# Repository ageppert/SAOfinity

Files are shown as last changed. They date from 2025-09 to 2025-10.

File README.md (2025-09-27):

# SAOfinity

An SAO display solution, with options!

-------------

# V1.0 First Draft - Shared at Hackaday Supercon.9 in 2025

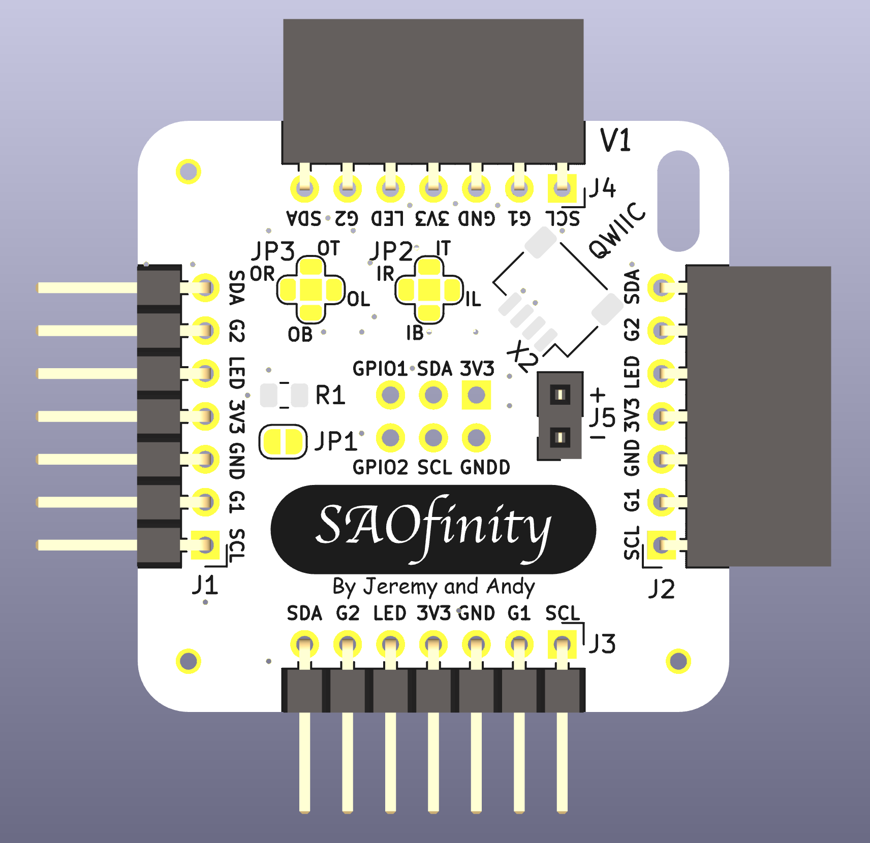
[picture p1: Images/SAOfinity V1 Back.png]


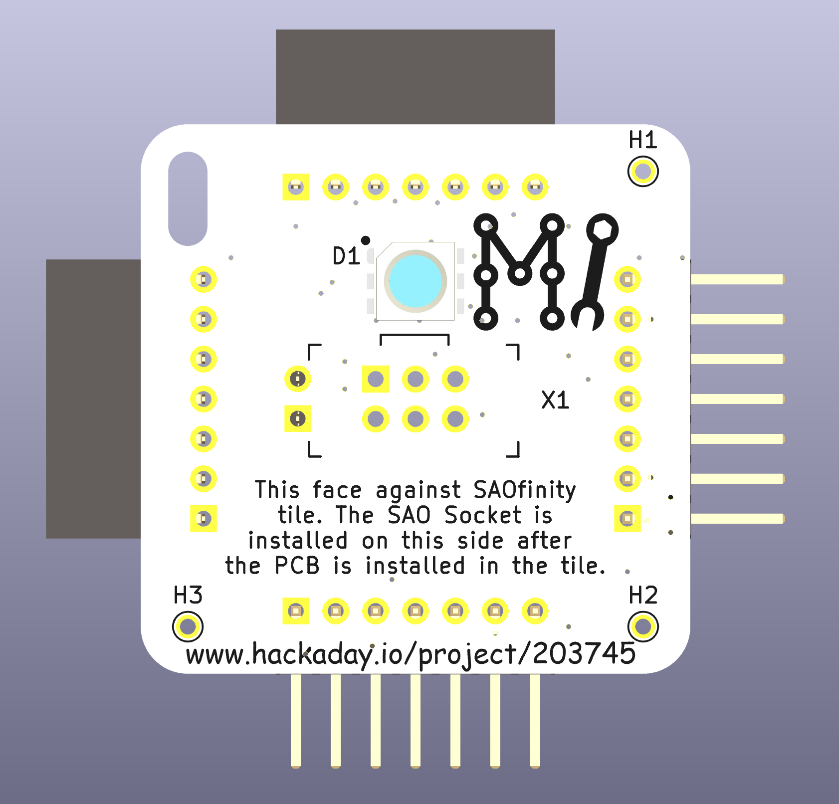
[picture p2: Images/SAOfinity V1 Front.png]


The SAO DEMO CONTROLLER is available for purchase here: https://www.tindie.com/products/36033/

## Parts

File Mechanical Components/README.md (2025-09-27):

# MECHANICAL COMPONENTS

3D printable SAOfinity components coming soon...

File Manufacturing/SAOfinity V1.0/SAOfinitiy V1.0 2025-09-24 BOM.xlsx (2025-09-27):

Comment | Designator | Footprint | LCSC Part Number | Substituted
WS2813C | D1 | LED_WS2813_PLCC6_5.0x5.0mm_P1.6mm_Core64_Abg_Mod | C5359034

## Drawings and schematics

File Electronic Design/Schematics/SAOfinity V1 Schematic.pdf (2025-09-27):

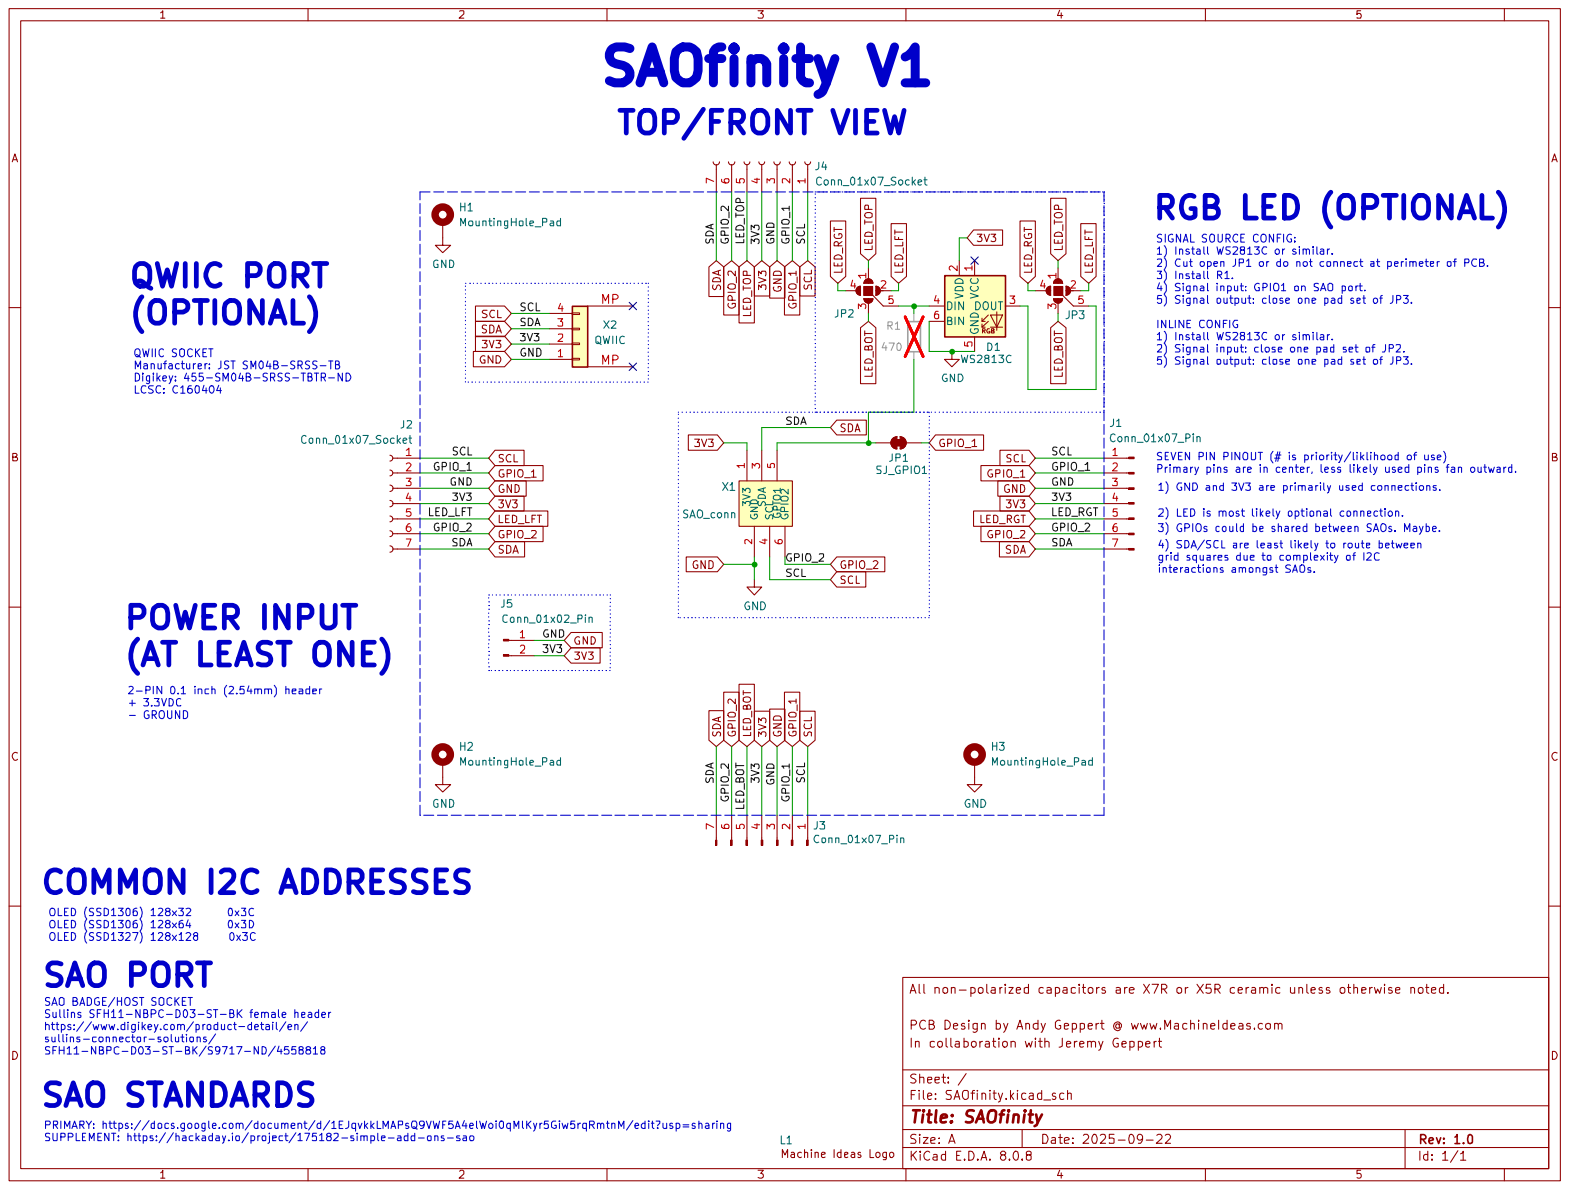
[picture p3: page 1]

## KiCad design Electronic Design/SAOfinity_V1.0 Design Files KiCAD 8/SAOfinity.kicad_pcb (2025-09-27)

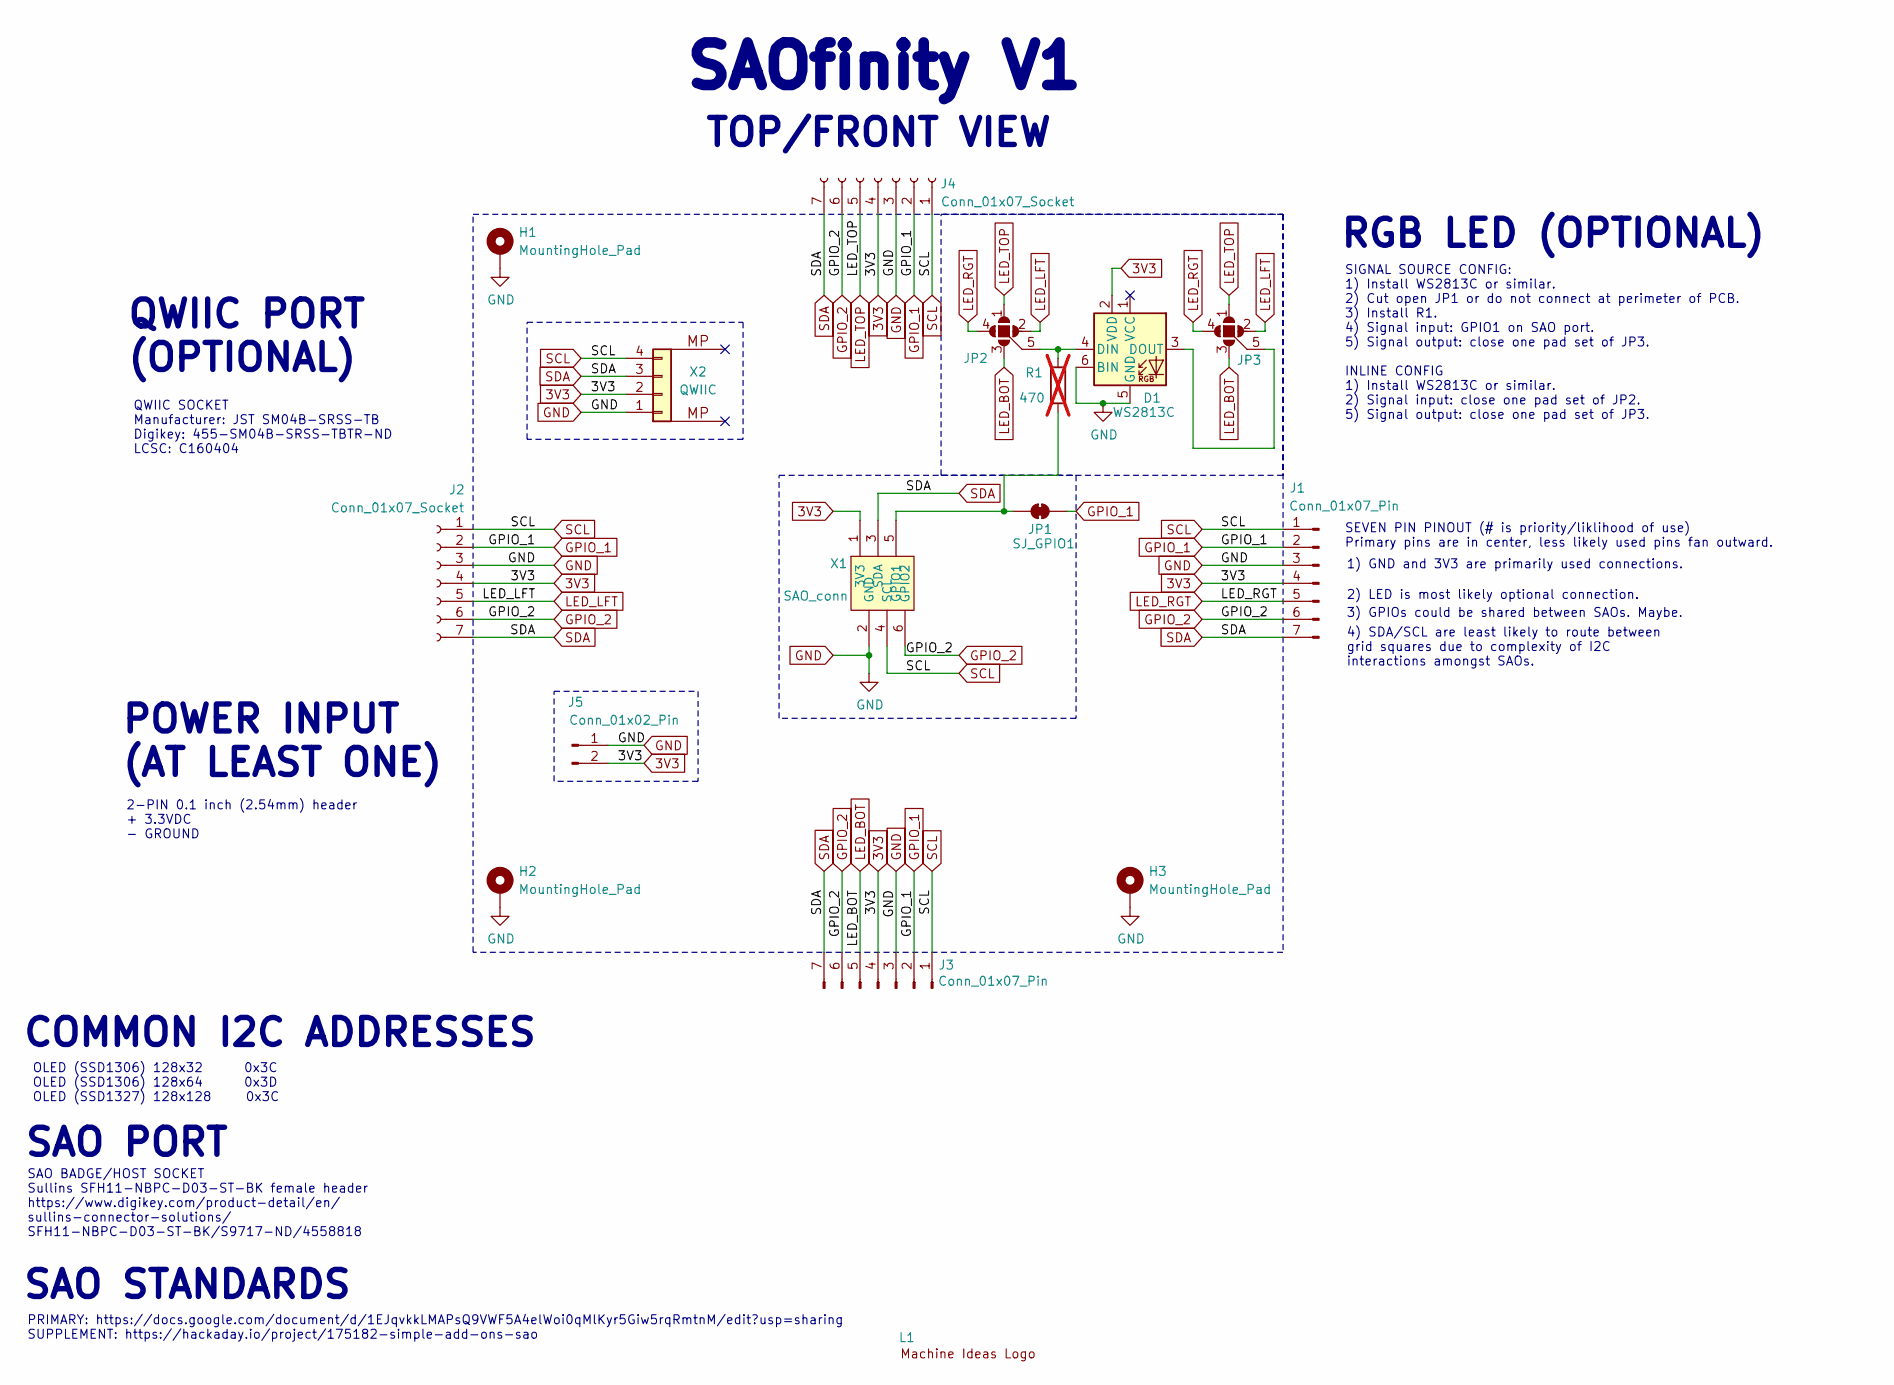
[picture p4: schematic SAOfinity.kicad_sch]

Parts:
D1: WS2813C; LED_WS2813_PLCC6_5.0x5.0mm_P1.6mm_Core64_Abg_Mod; JLCPCB P/N C5359034
H1, H2, H3: MountingHole_Pad; TestPoint_THTPad_D1.5mm_Drill1.0mm
J1, J3: Conn_01x07_Pin; PinHeader_1x07_P2.54mm_Horizontal
J2, J4: Conn_01x07_Socket; PinSocket_1x07_P2.54mm_Horizontal
J5: Conn_01x02_Pin; PinSocket_1x02_P2.54mm_Vertical
JP1: SJ_GPIO1; SolderJumper-2_P1.3mm_Bridged_RoundedPad1.0x1.5mm
JP2, JP3: SolderJumper_5_Open; SolderJumper-5_P1.3mm_Open_RoundedPad1.0x1.5mm_NumberLabels
L1: Machine_Ideas_logo
R1: 470; R_0805_2012Metric; LCSC C17710; not fitted
X1: SAO_conn; Badgelife-SAOv169-BADGE-2x3-no-front-text-yes-front-outline; MPN SFH11-NBPC-D03-ST-BK
X2: QWIIC; JST_SH_SM04B-SRSS-TB_1x04-1MP_P1.00mm_Horizontal; MPN SM04B-SRSS-TB; LCSC C160404

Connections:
3V3: D1.2 (VDD), J1.4, J2.4, J3.4, J4.4, J5.2, X1.1 (3V3), X2.2
GND: D1.5 (GND), D1.6 (BIN), H1.1, H2.1, H3.1, J1.3, J2.3, J3.3, J4.3, J5.1, X1.2 (GND), X2.1
GPIO_1: J1.2, J2.2, J3.2, J4.2, JP1.2 (B)
GPIO_2: J1.6, J2.6, J3.6, J4.6, X1.6 (GPIO2)
LED_BOT: J3.5, JP2.3 (C), JP3.3 (C)
LED_LFT: J2.5, JP2.2 (B), JP3.2 (B)
LED_RGT: J1.5, JP2.4 (D), JP3.4 (D)
LED_TOP: J4.5, JP2.1 (A), JP3.1 (A)
unnamed: D1.4 (DIN), JP2.5 (E), R1.2
unnamed: D1.3 (DOUT), JP3.5 (E)
unnamed: JP1.1 (A), R1.1, X1.5 (GPIO1)
SCL: J1.1, J2.1, J3.1, J4.1, X1.4 (SCL), X2.4
SDA: J1.7, J2.7, J3.7, J4.7, X1.3 (SDA), X2.3

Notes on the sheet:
RGB LED (OPTIONAL)
SAO BADGE/HOST SOCKET Sullins SFH11-NBPC-D03-ST-BK female header https://www.digikey.com/product-detail/en/ sullins-connector-solutions/ SFH11-NBPC-D03-ST-BK/S9717-ND/4558818
COMMON I2C ADDRESSES
QWIIC SOCKET Manufacturer: JST SM04B-SRSS-TB Digikey: 455-SM04B-SRSS-TBTR-ND LCSC: C160404
3) GPIOs could be shared between SAOs. Maybe.
2) LED is most likely optional connection.
4) SDA/SCL are least likely to route between grid squares due to complexity of I2C interactions amongst SAOs.
POWER INPUT (AT LEAST ONE)
OLED (SSD1306) 128x32 0x3C OLED (SSD1306) 128x64 0x3D OLED (SSD1327) 128x128 0x3C
SEVEN PIN PINOUT (# is priority/liklihood of use) Primary pins are in center, less likely used pins fan outward.
SAO STANDARDS
PRIMARY: https://docs.google.com/document/d/1EJqvkkLMAPsQ9VWF5A4elWoi0qMlKyr5Giw5rqRmtnM/edit?usp=sharing SUPPLEMENT: https://hackaday.io/project/175182-simple-add-ons-sao
TOP/FRONT VIEW
QWIIC PORT (OPTIONAL)
1) GND and 3V3 are primarily used connections.
2-PIN 0.1 inch (2.54mm) header + 3.3VDC - GROUND
SAO PORT
SIGNAL SOURCE CONFIG: 1) Install WS2813C or similar. 2) Cut open JP1 or do not connect at perimeter of PCB. 3) Install R1. 4) Signal input: GPIO1 on SAO port. 5) Signal output: close one pad set of JP3. INLINE CONFIG 1) Install WS2813C or similar. 2) Signal input: close one pad set of JP2. 5) Signa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
SAOfinity V1

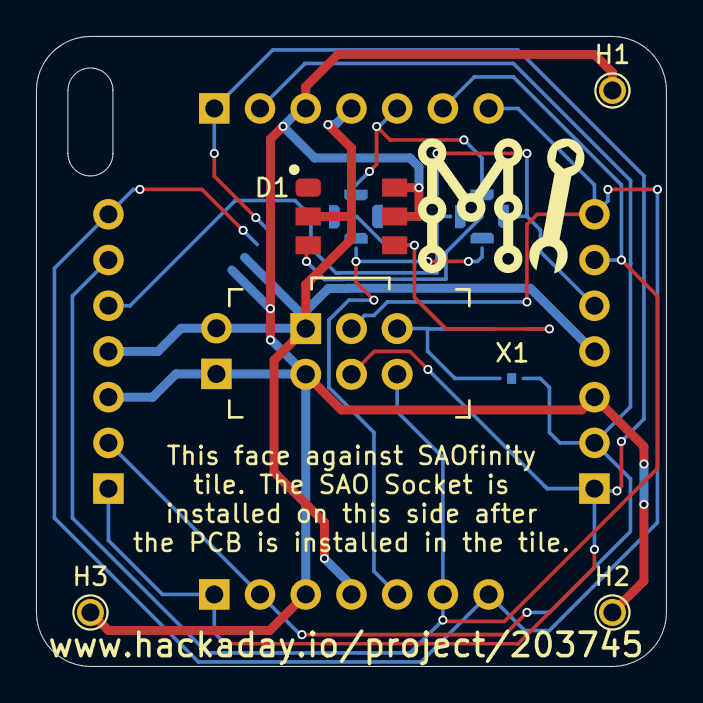
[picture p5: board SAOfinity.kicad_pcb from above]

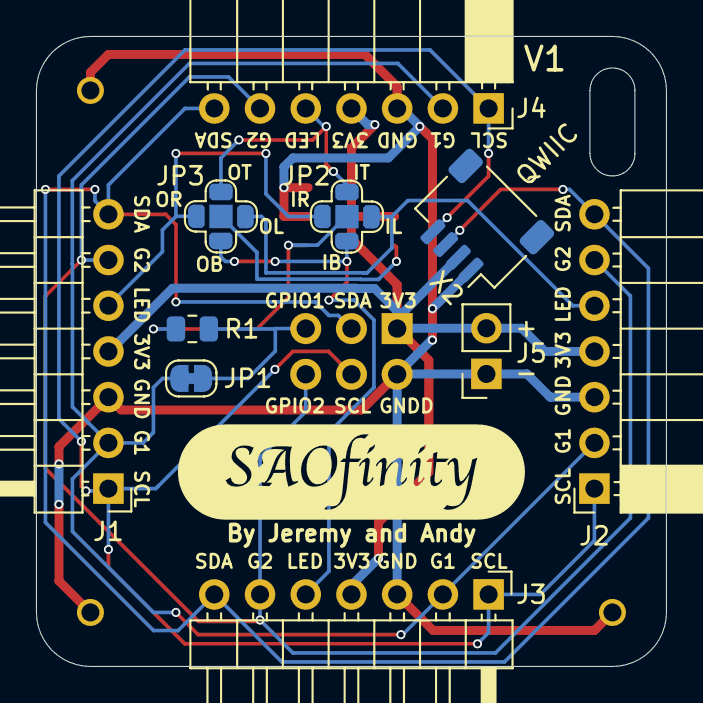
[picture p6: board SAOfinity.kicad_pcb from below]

Board: 2 copper layers, 35.0 x 35.0 mm, 17 parts (11 on the bottom side), 13 nets.

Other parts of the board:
kibuzzard-68D4AC2E: G***; kibuzzard-68D4AC2E

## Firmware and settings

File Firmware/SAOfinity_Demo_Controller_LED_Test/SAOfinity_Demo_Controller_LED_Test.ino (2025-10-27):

/*
This is Adafruit's "strandtest_nodelay" with small modifications by Andy to work with the SAO Demo Controller and SAOfinity.
SAOfinity: https://hackaday.io/project/203745-saofinity
SAO Demo Controller: https://hackaday.io/project/198034-sao-demo-controller 
First board in the SAOfinity strip needs a few mods and resistors to be the "source" for the strip. Details on SAOfinity page linked above.
Use Pin 1 for output to the LEDs from the SAO Demo Controller. Configured for 6x6 36 tile demo.
*/

// A non-blocking everyday NeoPixel strip test program.

// NEOPIXEL BEST PRACTICES for most reliable operation:
// - Add 1000 uF CAPACITOR between NeoPixel strip's + and - connections.
// - MINIMIZE WIRING LENGTH between microcontroller board and first pixel.
// - NeoPixel strip's DATA-IN should pass through a 300-500 OHM RESISTOR.
// - AVOID connecting NeoPixels on a LIVE CIRCUIT. If you must, ALWAYS
//   connect GROUND (-) first, then +, then data.
// - When using a 3.3V microcontroller with a 5V-powered NeoPixel strip,
//   a LOGIC-LEVEL CONVERTER on the data line is STRONGLY RECOMMENDED.
// (Skipping these may work OK on your workbench but can fail in the field)

#include <Adafruit_NeoPixel.h>
#ifdef __AVR__
 #include <avr/power.h> // Required for 16 MHz Adafruit Trinket
#endif

// Which pin on the Arduino is connected to the NeoPixels?
// On a Trinket or Gemma we suggest changing this to 1:
#ifdef ESP32
// Cannot use 6 as output for ESP. Pins 6-11 are connected to SPI flash. Use 16 instead.
#define LED_PIN    16
#else
#define LED_PIN    1
#endif

// How many NeoPixels are attached to the Arduino?
#define LED_COUNT 36

// Declare our NeoPixel strip object:
Adafruit_NeoPixel strip(LED_COUNT, LED_PIN, NEO_GRB + NEO_KHZ800);
// Argument 1 = Number of pixels in NeoPixel strip
// Argument 2 = Arduino pin number (most are valid)
// Argument 3 = Pixel type flags, add together as needed:
//   NEO_KHZ800  800 KHz bitstream (most NeoPixel products w/WS2812 LEDs)
//   NEO_KHZ400  400 KHz (classic 'v1' (not v2) FLORA pixels, WS2811 drivers)
//   NEO_GRB     Pixels are wired for GRB bitstream (most NeoPixel products)
//   NEO_RGB     Pixels are wired for RGB bitstream (v1 FLORA pixels, not v2)
//   NEO_RGBW    Pixels are wired for RGBW bitstream (NeoPixel RGBW products)

unsigned long pixelPrevious = 0;        // Previous Pixel Millis
unsigned long patternPrevious = 0;      // Previous Pattern Millis
int           patternCurrent = 0;       // Current Pattern Number
int           patternInterval = 5000;   // Pattern Interval (ms)
bool          patternComplete = false;

int           pixelInterval = 50;       // Pixel Interval (ms)
int           pixelQueue = 0;           // Pattern Pixel Queue
int           pixelCycle = 0;           // Pattern Pixel Cycle
uint16_t      pixelNumber = LED_COUNT;  // Total Number of Pixels

// setup() function -- runs once at startup --------------------------------
void setup() {
  // These lines are specifically to support the Adafruit Trinket 5V 16 MHz.
  // Any other board, you can remove this part (but no harm leaving it):
#if defined(__AVR_ATtiny85__) && (F_CPU == 16000000)
  clock_prescale_set(clock_div_1);
#endif
  // END of Trinket-specific code.

  delay(500);               // Delay to avoid issues with data line on the NeoPixels, doesn't seem to help.
  strip.begin();           // INITIALIZE NeoPixel strip object (REQUIRED)
  strip.show();            // Turn OFF all pixels ASAP
  strip.setBrightness(50); // Set BRIGHTNESS to about 1/5 (max = 255)
}

// loop() function -- runs repeatedly as long as board is on ---------------
void loop() {
  unsigned long currentMillis = millis();                     //  Update current time
  if( patternComplete || (currentMillis - patternPrevious) >= patternInterval) {  //  Check for expired time
    patternComplete = false;
    patternPrevious = currentMillis;
    patternCurrent++;                                         //  Advance to next pattern
    if(patternCurrent >= 7)
      patternCurrent = 0;
  }

  if(currentMillis - pixelPrevious >= pixelInterval) {        //  Check for expired time
    pixelPrevious = currentMillis;                            //  Run current frame
    switch (patternCurrent) {
      case 7:
        theaterChaseRainbow(50); // Rainbow-enhanced theaterChase variant
        break;
      case 6:
        rainbow(10); // Flowing rainbow cycle along the whole strip
        break;     
      case 5:
        theaterChase(strip.Color(0, 0, 127), 50); // Blue
        break;
      case 4:
        theaterChase(strip.Color(127, 0, 0), 50); // Red
        break;
      case 3:
        theaterChase(strip.Color(127, 127, 127), 50); // White
        break;
      case 2:
        colorWipe(strip.Color(0, 0, 255), 50); // Blue
        break;
      case 1:
        colorWipe(strip.Color(0, 255, 0), 50); // Green
        break;        
      default:
        colorWipe(strip.Color(255, 0, 0), 50); // Red
        break;
    }
  }
}

// Some functions of our own for creating animated effects -----------------

// Fill strip pixels one after another with a color. Strip is NOT cleared
// first; anything there will be covered pixel by pixel. Pass in color
// (as a single 'packed' 32-bit value, which you can get by calling
// strip.Color(red, green, blue) as shown in the loop() function above),
// and a delay time (in milliseconds) between pixels.
void colorWipe(uint32_t color, int wait) {
  static uint16_t current_pixel = 0;
  pixelInterval = wait;                        //  Update delay time
  strip.setPixelColor(current_pixel++, color); //  Set pixel's color (in RAM)
  strip.show();                                //  Update strip to match
  if(current_pixel >= pixelNumber) {           //  Loop the pattern from the first LED
    current_pixel = 0;
    patternComplete = true;
  }
}

// Theater-marquee-style chasing lights. Pass in a color (32-bit value,
// a la strip.Color(r,g,b) as mentioned above), and a delay time (in ms)
// between frames.
void theaterChase(uint32_t color, int wait) {
  static uint32_t loop_count = 0;
  static uint16_t current_pixel = 0;

  pixelInterval = wait;                   //  Update delay time

  strip.clear();

  for(int c=current_pixel; c < pixelNumber; c += 3) {
    strip.setPixelColor(c, color);
  }
  strip.show();

  current_pixel++;
  if (current_pixel >= 3) {
    current_pixel = 0;
    loop_count++;
  }

  if (loop_count >= 10) {
    current_pixel = 0;
    loop_count = 0;
    patternComplete = true;
  }
}

// Rainbow cycle along whole strip. Pass delay time (in ms) between frames.
void rainbow(uint8_t wait) {
  if(pixelInterval != wait)
    pixelInterval = wait;                   
  for(uint16_t i=0; i < pixelNumber; i++) {
    strip.setPixelColor(i, Wheel((i + pixelCycle) & 255)); //  Update delay time  
  }
  strip.show();                             //  Update strip to match
  pixelCycle++;                             //  Advance current cycle
  if(pixelCycle >= 256)
    pixelCycle = 0;                         //  Loop the cycle back to the begining
}

//Theatre-style crawling lights with rainbow effect
void theaterChaseRainbow(uint8_t wait) {
  if(pixelInterval != wait)
    pixelInterval = wait;                   //  Update delay time  
  for(int i=0; i < pixelNumber; i+=3) {
    strip.setPixelColor(i + pixelQueue, Wheel((i + pixelCycle) % 255)); //  Update delay time  
  }
  strip.show();
  for(int i=0; i < pixelNumber; i+=3) {
    strip.setPixelColor(i + pixelQueue, strip.Color(0, 0, 0)); //  Update delay time  
  }      
  pixelQueue++;                           //  Advance current queue  
  pixelCycle++;                           //  Advance current cycle
  if(pixelQueue >= 3)
    pixelQueue = 0;                       //  Loop
  if(pixelCycle >= 256)
    pixelCycle = 0;                       //  Loop
}

// Input a value 0 to 255 to get a color value.
// The colours are a transition r - g - b - back to r.
uint32_t Wheel(byte WheelPos) {
  WheelPos = 255 - WheelPos;
  if(WheelPos < 85) {
    return strip.Color(255 - WheelPos * 3, 0, WheelPos * 3);
  }
  if(WheelPos < 170) {
    WheelPos -= 85;
    return strip.Color(0, WheelPos * 3, 255 - WheelPos * 3);
  }
  WheelPos -= 170;
  return strip.Color(WheelPos * 3, 255 - WheelPos * 3, 0);
}

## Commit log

2025-09-27 Initial release with V1 files
    [SAOfinitiy V1.0 2025-09-24 BOM.xlsx, SAOfinity.kicad_pcb, SAOfinity.kicad_sch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]
2025-09-29 Add LED Datasheet
